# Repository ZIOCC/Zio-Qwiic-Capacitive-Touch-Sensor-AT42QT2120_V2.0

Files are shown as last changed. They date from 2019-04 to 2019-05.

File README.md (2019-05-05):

## Zio Qwiic Capacitive Touch Sensor AT42QT2120 V2.0
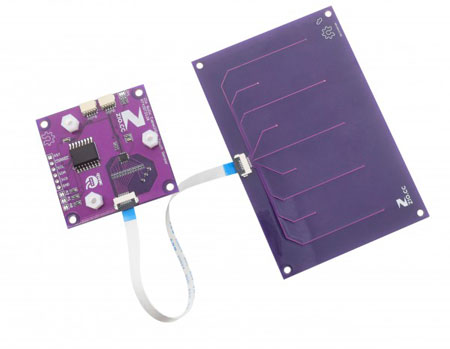
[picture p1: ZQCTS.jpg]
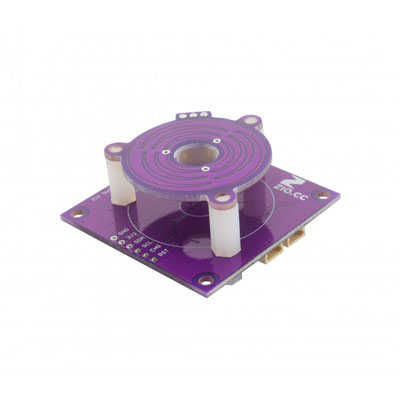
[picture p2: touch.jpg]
 

This product can be available for purchase [here](https://www.smart-prototyping.com/Zio-Qwiic-Capacitive-Touch-Sensor-Module-AT42QT2120).

### Description

This is a Qwiic version of the touch sensor based on the AT42QT2120 sensor. It can sense up to 12 keys, dependent on mode. Three of the keys can be used as sense channels for a slider or wheel, and 9 standard touch keys.

The Touch Wheel in this sensor is unique and different from other similar looking wheel sensors in terms of its added functionality. It can also be applied to create applications that need volume adjustment, light brightness, or wheel lights.

We’ve prepared the touch wheel and the keyboard for you and also included the source PCB file on our GitHub page for easy customization.

### Specifications

* IC :  AT42QT2120 & PCF8574T
* Default I2C Address: 0x1c & 0x23
* Operation Voltage: 3.3V
* Main board 
    - Dimension: 46.7 x 46.7mm
    - Weight: 7.6g
* Wheel touchpad: 
    - 0-255 ADC output, 
    - Dimension: 33.8mm diameter
    - Weight: 4.3g
* Keyboard, 
    - 9 keys, from key 4 to key 11
    - Dimension: 66.9 x 99.8mm 
    - Weight: 22.3g

###### About Zio
> Zio is a new line of open sourced, compact, and grid layout boards, fully integrated for Arduino and Qwiic ecosystem. Designed ideally for wearables, robotics, small-space limitations or other on the go projects. Check out other awesome Zio products [here](https://www.smart-prototyping.com/Zio).

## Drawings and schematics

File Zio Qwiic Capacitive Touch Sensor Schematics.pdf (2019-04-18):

# MODE 10 U1

# 9 J4

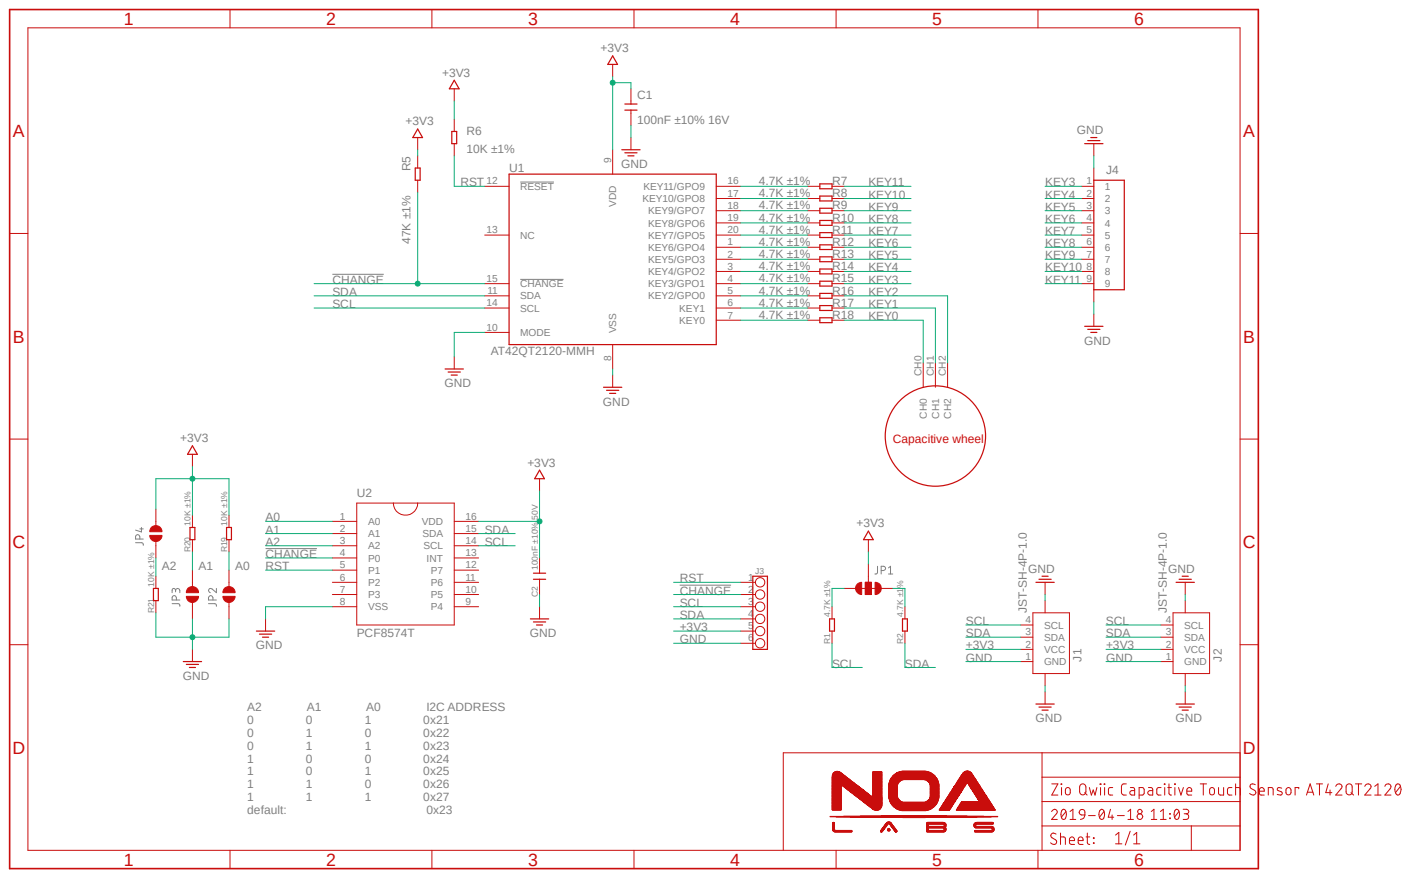
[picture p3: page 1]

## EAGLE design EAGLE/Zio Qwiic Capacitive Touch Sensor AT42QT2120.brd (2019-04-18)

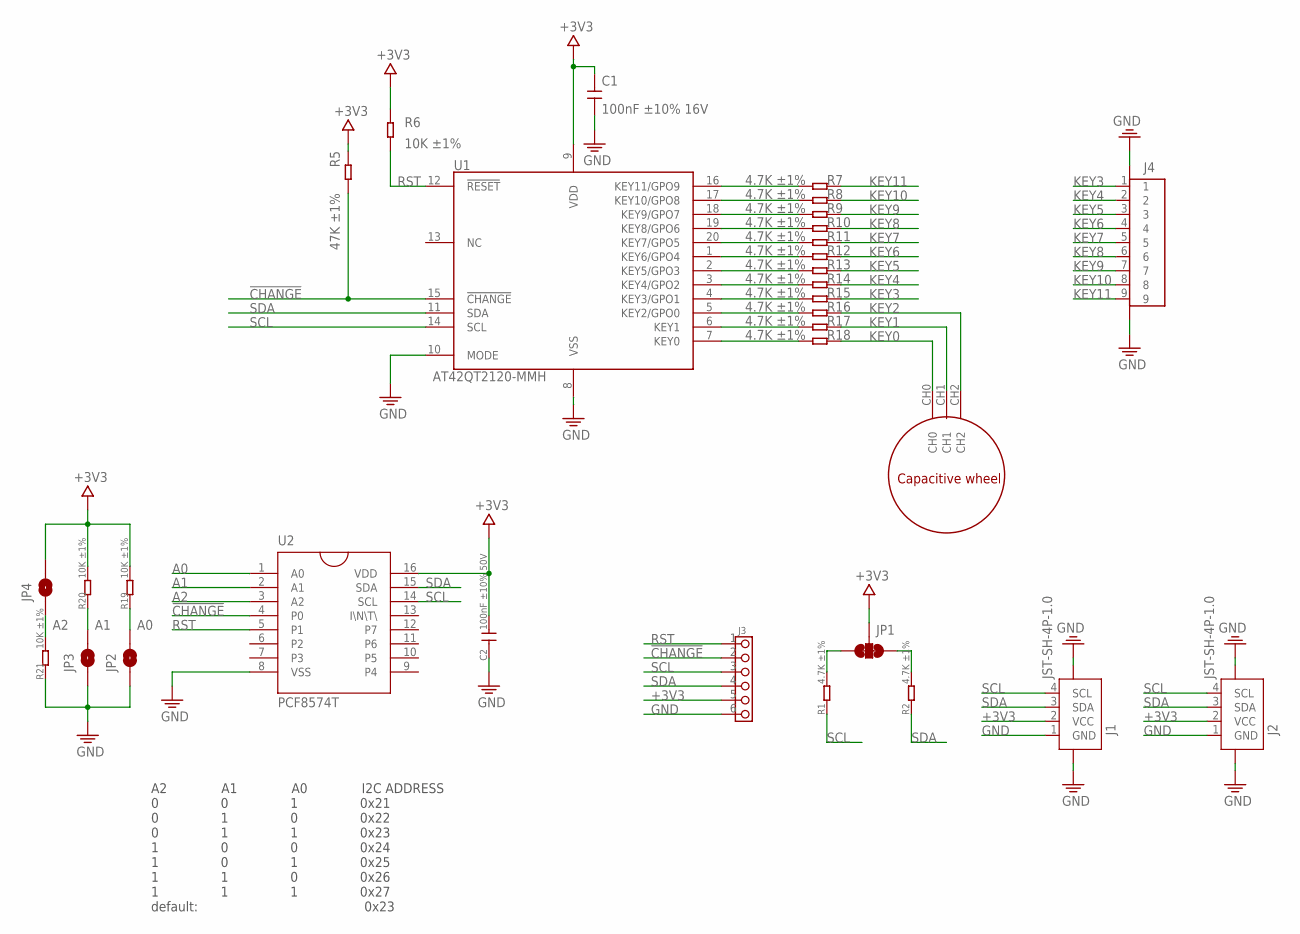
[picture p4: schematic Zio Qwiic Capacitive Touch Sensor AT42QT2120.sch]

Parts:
C1: 100nF ±10% 16V; C0603; VOLTAGE 25V
C2: 100nF ±10% 50V; C0603
J1, J2: JST-SH-4P-1.0; JST-SH-4P
J3: HEADER-6P-60/35MIL; 6P-2.54-60/35MIL
J4: FPC-0.5-9P; FPC-0.5-9P_UP
JP1: SMT-JUMPER_3_2-NC_TRACE
JP2, JP3, JP4: JUMPER-SMT_2_NC_PASTE_NOCREM; SMT-JUMPER_2_NC_PASTE_SILK_NOCREM
R1, R2: 4.7K ±1%; R0603
R5: 47K ±1%; R0603
R6, R19, R20, R21: 10K ±1%; R0603
R7, R8, R9, R10, R11, R12, R13, R14, R15, R16, R17, R18: 4.7K ±1%; R0402
U1: AT42QT2120-MMH; QFN45P300X300X85-21N
U2: PCF8574T; SO16-W
U3: QTWHEEL_MODULE; QTWHEELMODULE

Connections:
!CHANGE: J3.2, R5.1, U1.15 (!CHANGE), U2.4 (P0)
+3V3: C1.1, C2.2, J1.2 (VCC), J2.2 (VCC), J3.5, JP1.2, JP4.2, R5.2, R6.2, R19.2, R20.2, U1.9 (VDD), U2.16 (VDD)
A0: JP2.2, R19.1, U2.1 (A0)
A1: JP3.2, R20.1, U2.2 (A1)
A2: JP4.1, R21.2, U2.3 (A2)
GND: C1.2, C2.1, J1.1 (GND), J1.NC1 (5), J1.NC2 (6), J2.1 (GND), J2.NC1 (5), J2.NC2 (6), J3.6, J4.11 (G2), JP2.1, JP3.1, R21.1, U1.8 (VSS), U1.10 (MODE), U2.8 (VSS)
KEY0: R18.1, U3.CH0
KEY1: R17.1, U3.CH1
KEY2: R16.1, U3.CH2
KEY3: J4.1, R15.1
KEY4: J4.2, R14.1
KEY5: J4.3, R13.1
KEY6: J4.4, R12.1
KEY7: J4.5, R11.1
KEY8: J4.6, R10.1
KEY9: J4.7, R9.1
KEY10: J4.8, R8.1
KEY11: J4.9, R7.1
unnamed: JP1.1, R2.2
unnamed: JP1.3, R1.2
unnamed: R7.2, U1.16 (KEY11/GPO9)
unnamed: R8.2, U1.17 (KEY10/GPO8)
unnamed: R9.2, U1.18 (KEY9/GPO7)
unnamed: R10.2, U1.19 (KEY8/GPO6)
unnamed: R11.2, U1.20 (KEY7/GPO5)
unnamed: R12.2, U1.1 (KEY6/GPO4)
unnamed: R13.2, U1.2 (KEY5/GPO3)
unnamed: R14.2, U1.3 (KEY4/GPO2)
unnamed: R15.2, U1.4 (KEY3/GPO1)
unnamed: R16.2, U1.5 (KEY2/GPO0)
unnamed: R17.2, U1.6 (KEY1)
unnamed: R18.2, U1.7 (KEY0)
RST: J3.1, R6.1, U1.12 (!RESET), U2.5 (P1)
SCL: J1.4 (SCL), J2.4 (SCL), J3.3, R1.1, U1.14 (SCL), U2.14 (SCL)
SDA: J1.3 (SDA), J2.3 (SDA), J3.4, R2.1, U1.11 (SDA), U2.15 (SDA)

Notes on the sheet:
A2 A1 A0 I2C ADDRESS 0 0 1 0x21 0 1 0 0x22 0 1 1 0x23 1 0 0 0x24 1 0 1 0x25 1 1 0 0x26 1 1 1 0x27 default: 0x23

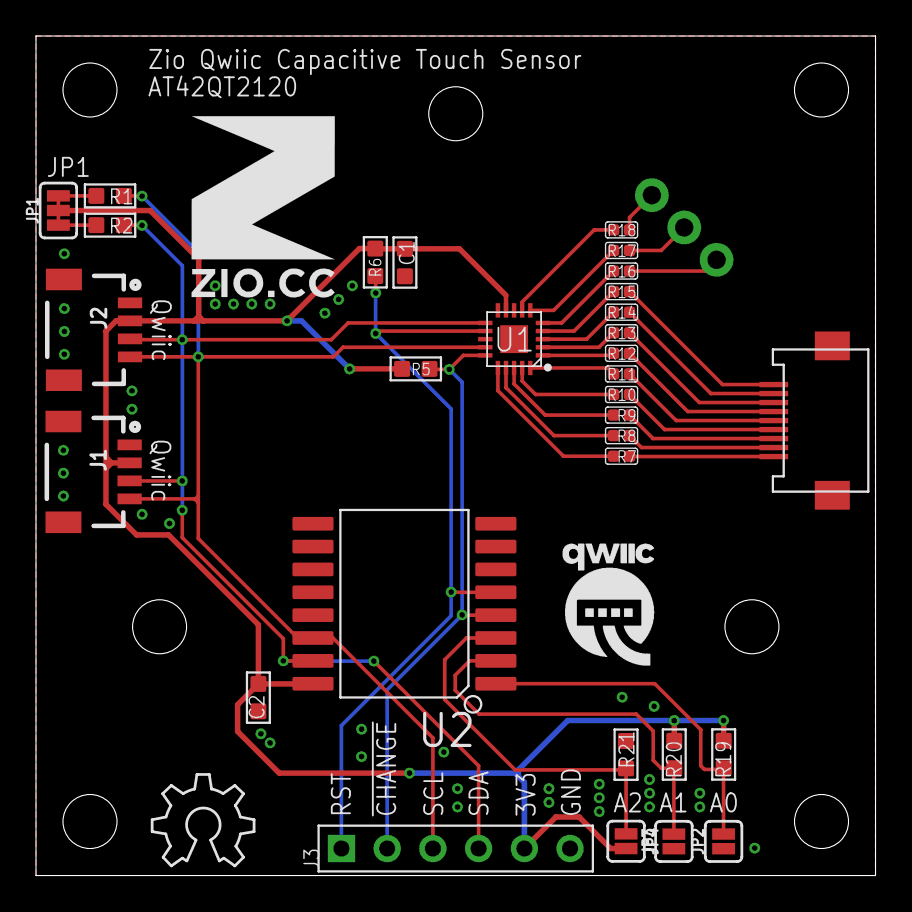
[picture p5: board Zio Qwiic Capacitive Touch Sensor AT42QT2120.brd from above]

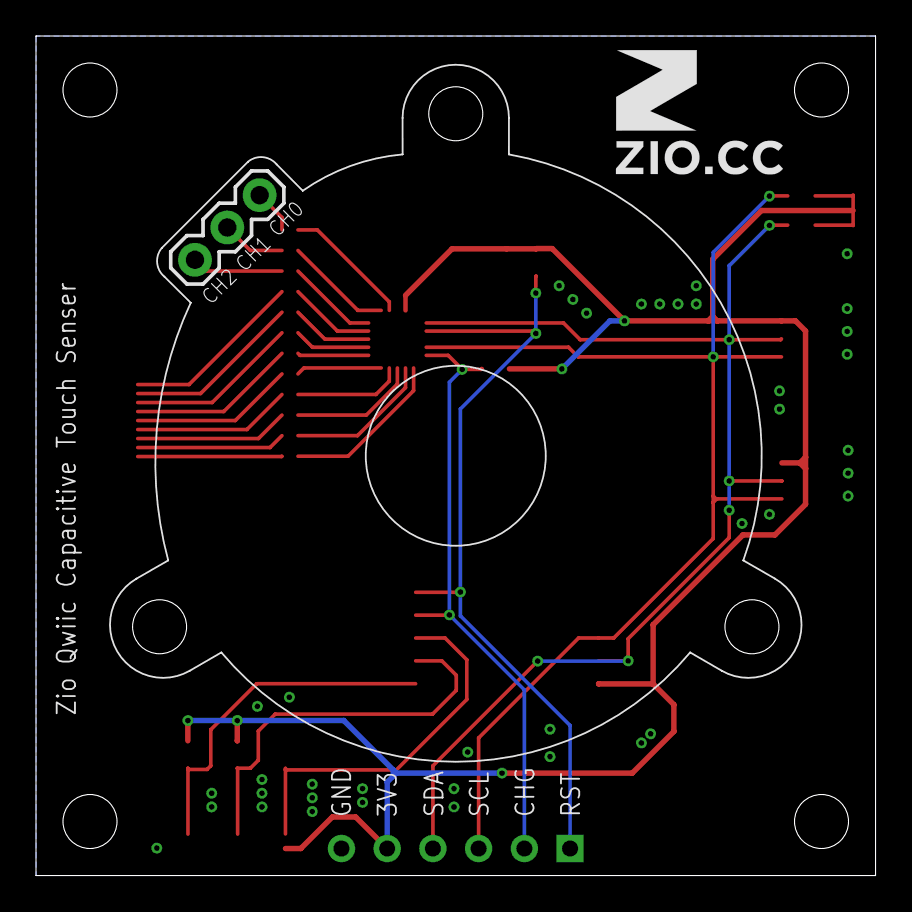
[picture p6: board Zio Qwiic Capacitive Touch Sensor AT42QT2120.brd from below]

Board: 2 copper layers, 46.6 x 46.6 mm, 36 parts (2 on the bottom side), 35 nets.

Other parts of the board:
U$1: 7MM
U$2: 10MM
U$3: OSHW_6X200_NOTEXT
U$4: QWIIC-LOGO-MEDIUM

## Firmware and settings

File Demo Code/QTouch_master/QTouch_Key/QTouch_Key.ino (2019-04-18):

#include "Appfruits_QTouch.h"
#include "TouchWheel.h"

Appfruits_QTouch qtouch = Appfruits_QTouch();
TouchWheel touchWheel(&qtouch);

void setup() {
  // put your setup code here, to run once:
  //Initialize Serial
  Serial.begin(115200);
  Serial.println("QTouch test");
  //Initialize I2C
  Wire.begin();
  qtouch.begin();
  pinMode(13,OUTPUT);
}

void loop() {
  // put your main code here, to run repeatedly:
  while(qtouch.eventAvailable())
  {
    Serial.println("TOUCHING...");
   
    for(uint8_t i=0;i<12;i++)
    {
      Serial.print("Key");
      Serial.print(i);
      Serial.print(": " );
      Serial.println(qtouch.isKeyPressed(i));
      }
    digitalWrite(13,HIGH);

  }
  digitalWrite(13,LOW);
}

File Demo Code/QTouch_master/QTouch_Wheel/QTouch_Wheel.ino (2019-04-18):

#include "Appfruits_QTouch.h"
#include "TouchWheel.h"

Appfruits_QTouch qtouch = Appfruits_QTouch();
TouchWheel touchWheel(&qtouch);

void setup() {
  // put your setup code here, to run once:
  //Initialize Serial
  Serial.begin(115200);
  Serial.println("QTouch test");
  //Initialize I2C
  Wire.begin();
  qtouch.begin();
  touchWheel.begin();
  pinMode(13,OUTPUT);
}

void loop() {
  // put your main code here, to run repeatedly:
  while(qtouch.eventAvailable())
  {
    //Serial.println("TOUCHING...");
//    Serial.println(qtouch.getDetectThreshold(0));
//    Serial.println(qtouch.getDetectionIntegrator());
   
//    for(uint8_t i=5;i<12;i++)
//    {
//      Serial.print("Key");
//      Serial.print(i);
//      Serial.print(": " );
//      Serial.println(qtouch.isKeyPressed(i));
//      }
//    for(uint8_t i=0;i<3;i++)
//    {
//      Serial.print("Key");
//      Serial.print(i);
//      Serial.print(": " );
//      Serial.println(qtouch.isKeyPressed(i));
//      }
    digitalWrite(13,HIGH);
    //Gather touch wheel events
    touchWheel.update();

    uint8_t P=touchWheel.getSliderPosition();
      Serial.println("TOUCHING...");
      Serial.println(P);
      
//    if (touchWheel.isButtonReleased(TouchWheel::Direction::Top))
//    {
//      Serial.println("Top");
//    }  
//    if (touchWheel.isButtonReleased(TouchWheel::Direction::Bottom))
//    {
//      Serial.println("Bottom");
//    }
//    if (touchWheel.isButtonReleased(TouchWheel::Direction::Left))
//    {
//      Serial.println("Left");
//    }  
//    if (touchWheel.isButtonReleased(TouchWheel::Direction::Right))
//    {
//      Serial.println("Right");
//    }
  
  //delay(200);
  }
  digitalWrite(13,LOW);
}
